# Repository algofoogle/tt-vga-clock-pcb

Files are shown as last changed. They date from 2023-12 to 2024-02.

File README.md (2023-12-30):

Matt Venn's ASIC VGA Clock
==========================

* World's first [certified open source hardware](https://certification.oshwa.org/es000023.html) down to the GDS?
* The original design was using an ASIC that was part of the Google sponsored MPW1. Due to [many issues with this first chip](https://www.zerotoasiccourse.com/post/mpw1_silicon/), the current version uses one from the [TinyTapeout 3p5](https://github.com/TinyTapeout/tinytapeout-03p5) experimental test.
* For more details about the design, see [VGA ASIC Clock](https://www.zerotoasiccourse.com/post/vga_clock/). 

# PCB

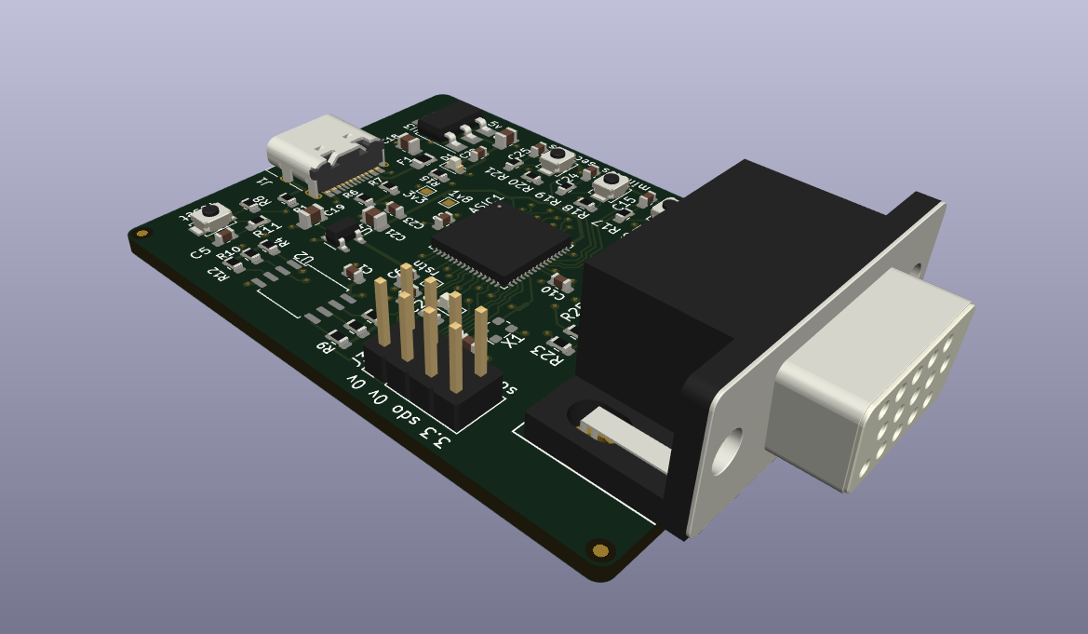
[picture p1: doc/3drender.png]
board


This PCB started by forking the https://github.com/TinyTapeout/caravel-mvp-pcb template repository. That provides all the minimal necessary components for the chip to work. 
This repo then adds the needed buttons and VGA connector for the clock design.

* [PDF Schematic](doc/schematic.pdf)

# Setup

## Firmware

This needs to be made public and the fw fixed to always select clock.

https://github.com/TinyTapeout/tt3p5-demo-fw/

## PLL config

Needs 31.5MHz for VGA signal. As precise as possible for good timekeeping.
A 9MHz oscillator should also work if using the chip's built in PLL.

Using https://github.com/kbeckmann/caravel-pll-calculator

    matt-desktop:2003 [main]: ./caravel_pll.py generate --clkout 31.5 --clkin 9
    PLL Parameters:

    clkin:    9.00 MHz
    clkout:   31.50 MHz
    clkout90: 31.50 MHz

    PLL Feedback Divider: 14
    PLL Output Divider 1: 4
    PLL Output Divider 2: 4

    Register 0x11: 0x24
    Register 0x12: 0x0e

## Pinning

The chip's pinout is here: https://github.com/TinyTapeout/tinytapeout-03p5/blob/main/verilog/rtl/user_defines.v

The definition of the clock design pins are here: https://github.com/TinyTapeout/tt03p5-vga-clock/blob/main/src/tt_vga_clock.v

### inputs

* 06 clock 
* 07 rst_n
* 08 hours
* 09 mins
* 10 sec

### outputs

* 16 hsync
* 17 vsync
* 18:23 rrggbb

# BOM

TBD

# Errata

# Resources

* Caravel datasheet: https://caravel-harness.readthedocs.io/en/latest
* Version 1 repository is here: https://github.com/mattvenn/vga_clock_pcb

# License

* The ASIC and PCB are licensed under the [Apache2 License](LICENSE)

# Open Source Hardware

This board is an OSHWA approved design: [ES000023](https://certification.oshwa.org/es000023.html)

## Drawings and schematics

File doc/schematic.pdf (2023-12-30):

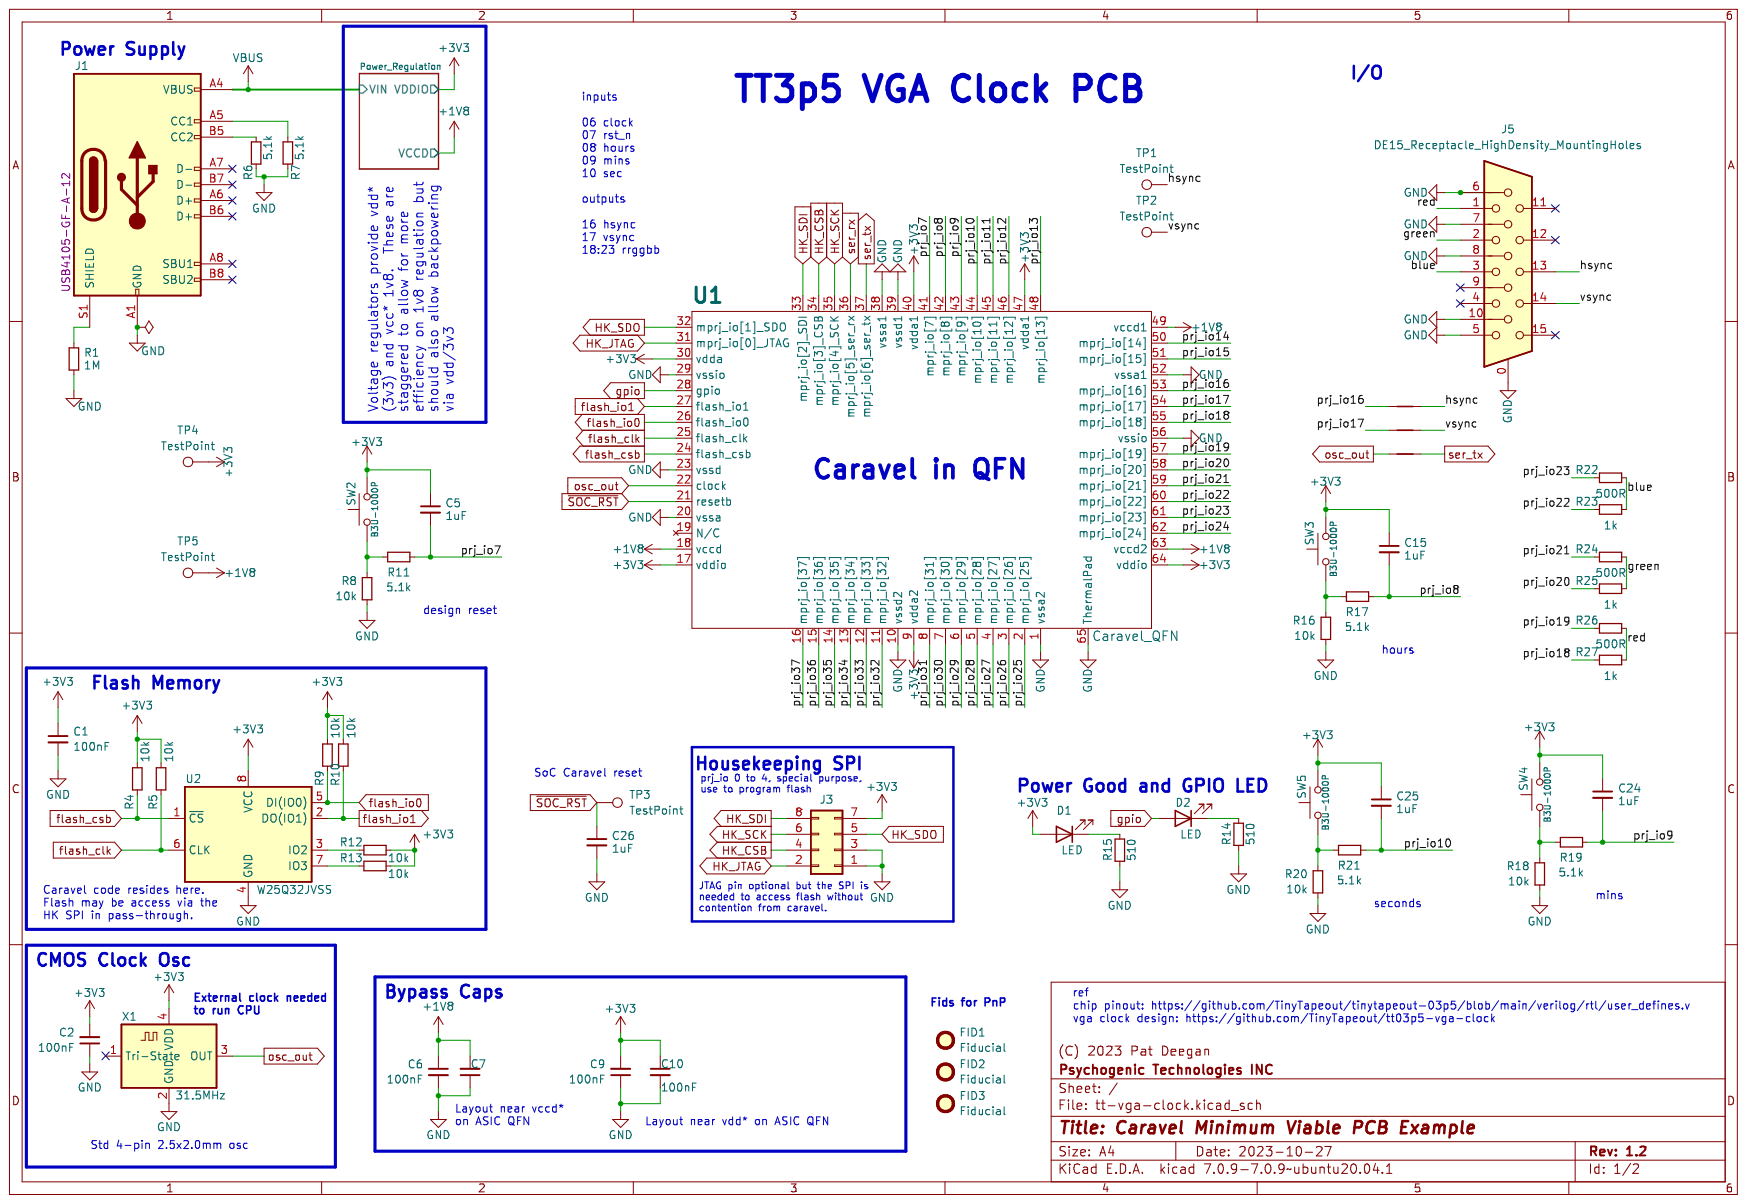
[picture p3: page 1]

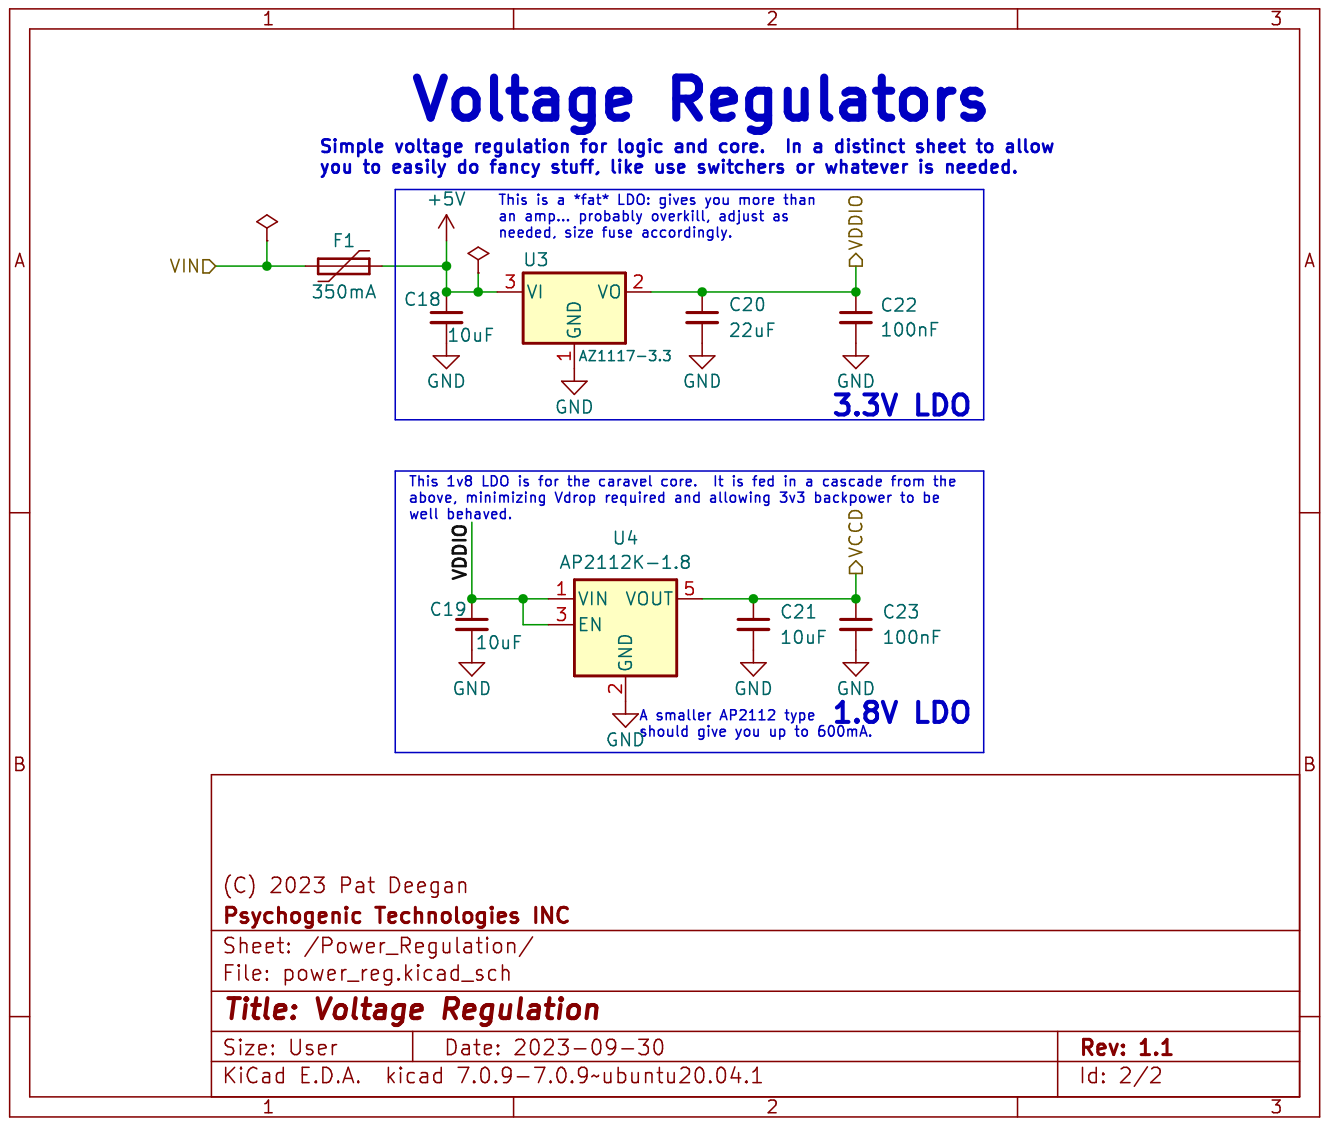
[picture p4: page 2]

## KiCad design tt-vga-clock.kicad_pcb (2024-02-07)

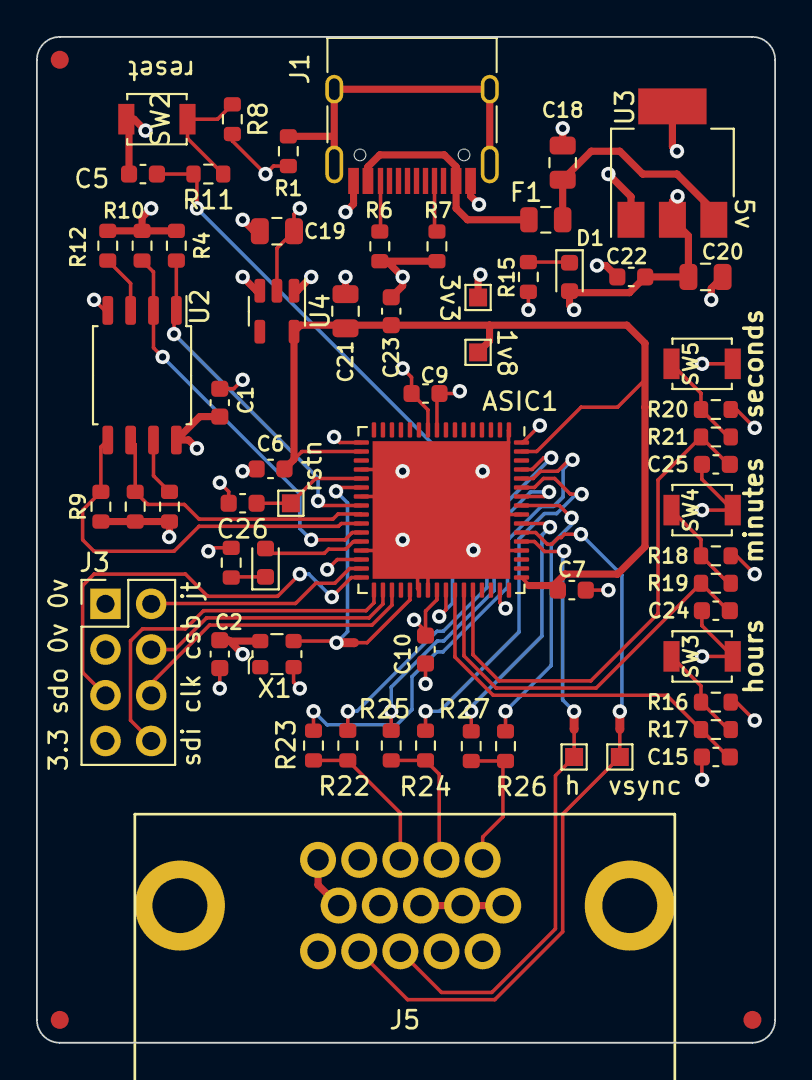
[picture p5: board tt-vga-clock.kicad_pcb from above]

Board: 4 copper layers, 41.0 x 55.9 mm, 68 parts (0 on the bottom side), 46 nets.

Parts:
C1, C2, C6, C7, C9, C10, C22, C23: 100nF; C_0603_1608Metric
C5, C15, C24, C25, C26: 1uF; C_0603_1608Metric
C18, C19, C21: 10uF; C_0805_2012Metric
C20: 22uF; C_0805_2012Metric
D1, D2: LED; LED_0603_1608Metric
F1: 350mA; Fuse_0805_2012Metric
FID1, FID2, FID3: Fiducial; Fiducial_1mm_Mask2mm
J1: USB_C_Receptacle_USB2.0; USB_C_Receptacle_HRO_TYPE-C-31-M-12
J3: Conn_02x04_Odd_Even; PinHeader_2x04_P2.54mm_Vertical
J5: DE15_Receptacle_HighDensity_MountingHoles; db15
NT1, NT2, NT3: NetTie_2; NetTie-2_SMD_Pad0.5mm
R1: 1M; R_0603_1608Metric
R4, R5, R8, R9, R10, R12, R13, R16, R18, R20: 10k; R_0603_1608Metric
R6, R7, R11, R17, R19, R21: 5.1k; R_0603_1608Metric
R14, R15: 510; R_0603_1608Metric
R22, R24, R26: 500R; R_0603_1608Metric
R23, R25, R27: 1k; R_0603_1608Metric
SW2, SW3, SW4, SW5: B3U-1000P; SW_SPST_B3U-1000P
TP1, TP2, TP3, TP4, TP5: TestPoint; TestPoint_Pad_1.0x1.0mm
U1: Caravel_QFN; QFN-64-1EP_9x9mm_P0.5mm_EP7.65x7.65mm
U2: W25Q32JVSS; SOIC-8_5.23x5.23mm_P1.27mm
U3: AZ1117-3.3; SOT-223-3_TabPin2
U4: AP2112K-1.8; SOT-23-5
X1: 31.5MHz; Oscillator_SMD_ECS_2520MV-xxx-xx-4Pin_2.5x2.0mm

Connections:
+1V8: C6.1, C7.2, C21.1, C23.1, TP5.1, U1.18 (vccd), U1.49 (vccd1), U1.63 (vccd2), U4.5 (VOUT)
+3V3: C1.1, C2.2, C5.1, C9.2, C10.1, C15.1, C19.1, C20.1, C22.1, C24.1, C25.1, D1.2 (A), J3.7, R4.1, R5.1, R9.1, R10.1, R12.2, R13.2, SW2.2, SW3.2, SW4.2, SW5.2, TP4.1, U1.9 (vdda2), U1.17 (vddio), U1.30 (vdda), U1.40 (vdda1), U1.47 (vdda1), U1.64 (vddio), U2.8 (VCC), U3.2 (VO), U4.1 (VIN), U4.3 (EN), X1.4 (VDD)
+5V: C18.1, F1.2, U3.3 (VI)
/blue: J5.3, R22.2, R23.2
/green: J5.2, R24.2, R25.2
/hsync: J5.13, NT1.2, TP1.1
/prj_io7: C5.2, R11.2, U1.41 (mprj_io[7])
/prj_io8: C15.2, R17.2, U1.42 (mprj_io[8])
/prj_io9: C24.2, R19.2, U1.43 (mprj_io[9])
/prj_io10: C25.2, R21.2, U1.44 (mprj_io[10])
/prj_io16: NT1.1, U1.53 (mprj_io[16])
/prj_io17: NT2.1, U1.54 (mprj_io[17])
/prj_io18: R27.1, U1.55 (mprj_io[18])
/prj_io19: R26.1, U1.57 (mprj_io[19])
/prj_io20: R25.1, U1.58 (mprj_io[20])
/prj_io21: R24.1, U1.59 (mprj_io[21])
/prj_io22: R23.1, U1.60 (mprj_io[22])
/prj_io23: R22.1, U1.61 (mprj_io[23])
/red: J5.1, R26.2, R27.2
/vsync: J5.14, NT2.2, TP2.1
GND: C1.2, C2.1, C6.2, C7.1, C9.1, C10.2, C18.2, C19.2, C20.2, C21.2, C22.2, C23.2, C26.2, J1.A1 (GND), J1.A12 (GND), J1.B1 (GND), J1.B12 (GND), J3.1, J3.3, J5.5, J5.6, J5.7, J5.8, J5.10, R1.2, R6.2, R7.2, R8.2, R14.2, R15.2, R16.2, R18.2, R20.2, U1.1 (vssa2), U1.10 (vssd2), U1.20 (vssa), U1.23 (vssd), U1.29 (vssio), U1.38 (vssa1), U1.39 (vssd1), U1.52 (vssa1), U1.56 (vssio), U1.65 (ThermalPad), U2.4 (GND), U3.1 (GND), U4.2 (GND), X1.2 (GND)
HK_CSB: J3.4, U1.34 (mprj_io[3]_CSB)
HK_JTAG: J3.2, U1.31 (mprj_io[0]_JTAG)
HK_SCK: J3.6, U1.35 (mprj_io[4]_SCK)
HK_SDI: J3.8, U1.33 (mprj_io[2]_SDI)
HK_SDO: J3.5, U1.32 (mprj_io[1]_SDO)
unnamed: D1.1 (K), R15.1
unnamed: D2.1 (K), R14.1
unnamed: J1.A5 (CC1), R7.1
unnamed: J1.B5 (CC2), R6.1
unnamed: J1.S1 (SHIELD), R1.1
unnamed: R8.1, R11.1, SW2.1
unnamed: R16.1, R17.1, SW3.1
unnamed: R18.1, R19.1, SW4.1
unnamed: R20.1, R21.1, SW5.1
unnamed: R12.1, U2.3 (IO2)
unnamed: R13.1, U2.7 (IO3)
VBUS: F1.1, J1.A4 (VBUS), J1.A9 (VBUS), J1.B4 (VBUS), J1.B9 (VBUS)
flash_clk: R5.2, U1.25 (flash_clk), U2.6 (CLK)
flash_csb: R4.2, U1.24 (flash_csb), U2.1 (~CS)
flash_io0: R9.2, U1.26 (flash_io0), U2.5 (DI(IO0))
flash_io1: R10.2, U1.27 (flash_io1), U2.2 (DO(IO1))
gpio: D2.2 (A), U1.28 (gpio)
osc_out: NT3.1, U1.22 (clock), X1.3 (OUT)
ser_tx: NT3.2, U1.37 (mprj_io[6]_ser_tx)
~SOC_RST: C26.1, TP3.1, U1.21 (resetb)

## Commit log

2023-12-27 pinout for buttons, delete unneeded parts
    [power_reg.kicad_sch, tt-vga-clock.kicad_pcb, tt-vga-clock.kicad_sch]
2023-12-27 schematic done
    [tt-vga-clock.kicad_pcb, tt-vga-clock.kicad_sch]
2023-12-28 start layout
    [power_reg.kicad_sch, tt-vga-clock.kicad_pcb, tt-vga-clock.kicad_sch]
2023-12-28 first pass layout
    [tt-vga-clock.kicad_pcb]
2023-12-28 oshw mark, better silk, edge cuts, all nets connected
    [tt-vga-clock.kicad_pcb, tt-vga-clock.kicad_sch]
2023-12-28 use correct db15 fp
    [tt-vga-clock.kicad_pcb, tt-vga-clock.kicad_sch]
2023-12-30 model for db15
    [tt-vga-clock.kicad_pcb]
2024-02-07 Increase space (ASIC east) for next rev; tidy west/south traces
    [tt-vga-clock.kicad_pcb]

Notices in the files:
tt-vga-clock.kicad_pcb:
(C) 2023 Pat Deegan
